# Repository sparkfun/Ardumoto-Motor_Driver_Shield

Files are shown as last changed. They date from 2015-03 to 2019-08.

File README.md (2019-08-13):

SparkFun Ardumoto - Motor Driver Shield
=======================================

SparkFun Ardumoto - Motor Driver Shield

[*SparkFun Ardumoto - Motor Driver Shield (DEV-14129)*](https://www.sparkfun.com/products/14129)

This is a motor shield for Arduino that will control two DC motors. 
Based on the L298 H-bridge, the SparkFun Ardumoto can drive up to 2 amps per channel. 

Repository Contents
-------------------
* **/Firmware** - Example Arduino sketch
* **/Hardware** - All Eagle design files (.brd, .sch)

Documentation
--------------
* [Hookup Guide](https://learn.sparkfun.com/tutorials/ardumoto-kit-hookup-guide)

Version History
---------------

* [HW_1.4_FW_1.0](https://github.com/sparkfun/Ardumoto-Motor_Driver_Shield/tree/HW_1.4_FW_1.0) - Version 1.4
* [V_2.0.0](https://github.com/sparkfun/Ardumoto-Motor_Driver_Shield/tree/V_2.0.0) - Initial build release
* [V_2.0.1](https://github.com/sparkfun/Ardumoto-Motor_Driver_Shield/tree/V_2.0.1) - Public release

License Information
-------------------
The hardware is released under [Creative Commons ShareAlike 4.0 International](https://creativecommons.org/licenses/by-sa/4.0/).
The code is beerware; if you see me (or any other SparkFun employee) at the local, and you've found our code helpful, please buy us a round!

Distributed as-is; no warranty is given.

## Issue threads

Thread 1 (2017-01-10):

Ardumoto_v15 Checklist

edspark, 2017-01-10:
1) Is there a SparkFun Logo? [YES]
comment: There are two logos on the second sheet, I'm not sure if you want them both.

2) Does it pass DRC with top/bottom keepout layers on? [YES]
comment: Plenty of approved erros centered around the many jumpers (funky library) and the 15 mill vias under the IC.

3) Are there airwires after ratsnest? [YES]
comment: I found two air wires and have attached images of them both.

4) Are measurements included for outer dimension and standoffs (Eagle layer 47)? [NO]
comment: There are missing measurements for the standoffs.

First air wire:
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

Second air wire:
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

marshalltaylorSFE, 2017-01-10:
1.  Switched sheets, moved one "logo" to the other sheet (these are really symbols to silk shapes)
2.  These approved violations are acceptable
3.  Airwires fixed!
4.  Measures added!

Closed 2017-01-10.

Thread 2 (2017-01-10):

Ardumoto Revision v15 Checklist

edspark, 2017-01-10:
1) If there are any DRC errors, have they all been approved? [YES]
comment: Many approved erros, double checked.

2) Is the designer name included in tDocu? [NO]
comment: "Pete Dokter" is not included in "Designed By"

3) Is any silkscreen overlaid on vias? [YES]
comment: Looks good for the silk that is partly covering vias.

marshalltaylorSFE, 2017-01-10:
1. OK
2. Name became buried under license after movement for measures, fixed.
3. "D7" is troublesome, but no better location is obvious, let's see how these look in proto hardware.

Closed 2017-01-10.

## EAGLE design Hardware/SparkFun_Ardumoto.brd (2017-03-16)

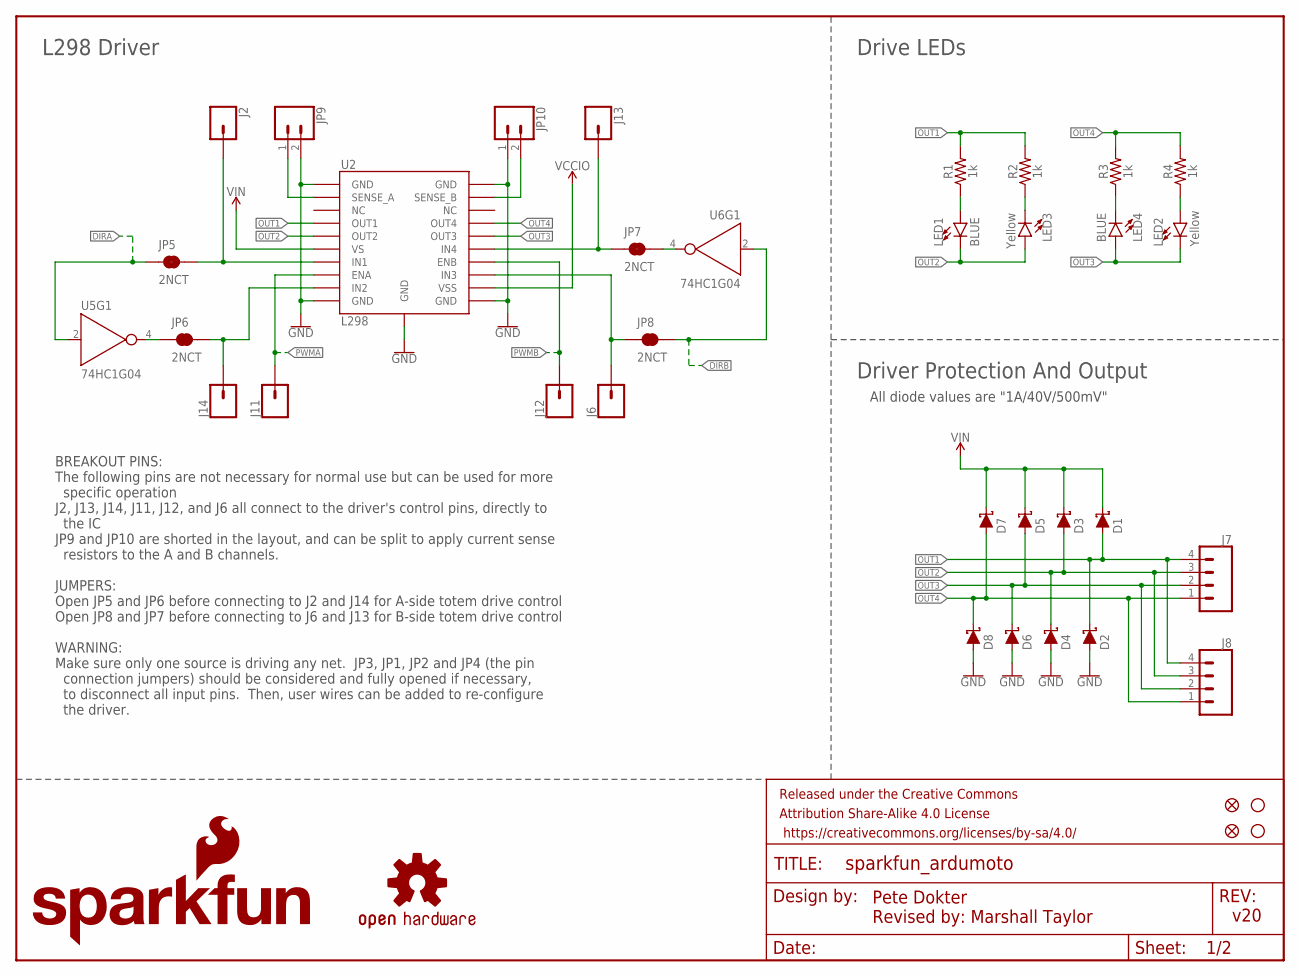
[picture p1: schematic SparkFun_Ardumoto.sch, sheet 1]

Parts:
D1, D2, D3, D4, D5, D6, D7, D8: 1A/40V/500mV; SMA-DIODE
FD1, FD2: FIDUCIALUFIDUCIAL; MICRO-FIDUCIAL
FRAME2: FRAME-LETTERNO_PACKAGE; DUMMY
H1, H2: STAND-OFF
J2, J6, J11, J12, J13, J14: CONN_01PTH_NO_SILK_YES_STOP; 1X01_NO_SILK
J7: CONN_04SCREW; SCREWTERMINAL-3.5MM-4
J8: CONN_04; 1X04
JP5, JP6, JP7, JP8: 2NCT; SMT-JUMPER_2_NC_TRACE_SILK
JP9, JP10: CONN_021X02_NO_SILK; 1X02_NO_SILK
LED1, LED4: BLUE; LED-0603
LED2, LED3: Yellow; LED-0603
LOGO2: SFE_LOGO_NAME_FLAME.1_INCH; SFE_LOGO_NAME_FLAME_.1
R1, R2, R3, R4: 1k; 0603
U2: L298; POWERSO20_L298_PAD
U5, U6: 74HC1G04; SOT353
U$1: OSHW-LOGOS; OSHW-LOGO-S

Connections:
DIRA: JP5.1, U5.2 (A); also elsewhere on the board
DIRB: JP8.2, U6.2 (A); also elsewhere on the board
GND: D2.A, D4.A, D6.A, D8.A, JP9.2, JP10.1, U2.1 (GND), U2.10 (GND), U2.11 (GND), U2.20 (GND), U2.PAD (GND); also elsewhere on the board
IN1: J2.1, JP5.2, U2.7 (IN1)
IN2: J14.1, JP6.2, U2.9 (IN2)
IN3: J6.1, JP8.1, U2.13 (IN3)
IN4: J13.1, JP7.1, U2.15 (IN4)
unnamed: LED1.A, R1.1
unnamed: LED3.C, R2.1
unnamed: LED4.C, R3.1
unnamed: LED2.A, R4.1
NDIRA: JP6.1, U5.4 (Y)
NDIRB: JP7.2, U6.4 (Y)
OUT1: D1.A, D2.C, J7.4, J8.4, R1.2, R2.2, U2.4 (OUT1)
OUT2: D3.A, D4.C, J7.3, J8.3, LED1.C, LED3.A, U2.5 (OUT2)
OUT3: D5.A, D6.C, J7.2, J8.2, LED2.C, LED4.A, U2.16 (OUT3)
OUT4: D7.A, D8.C, J7.1, J8.1, R3.2, R4.2, U2.17 (OUT4)
PWMA: J11.1, U2.8 (ENA); also elsewhere on the board
PWMB: J12.1, U2.14 (ENB); also elsewhere on the board
SENA: JP9.1, U2.2 (SENSE_A)
SENB: JP10.2, U2.19 (SENSE_B)
VCCIO: U2.12 (VSS); also elsewhere on the board
VIN: D1.C, D3.C, D5.C, D7.C, U2.6 (VS); also elsewhere on the board

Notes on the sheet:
v20
Revised by: Marshall Taylor
Pete Dokter
BREAKOUT PINS: The following pins are not necessary for normal use but can be used for more specific operation J2, J13, J14, J11, J12, and J6 all connect to the driver's control pins, directly to the IC JP9 and JP10 are shorted in the layout, and can be split to apply current sense resistors to the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
L298 Driver
Driver Protection And Output
Drive LEDs
All diode values are "1A/40V/500mV"

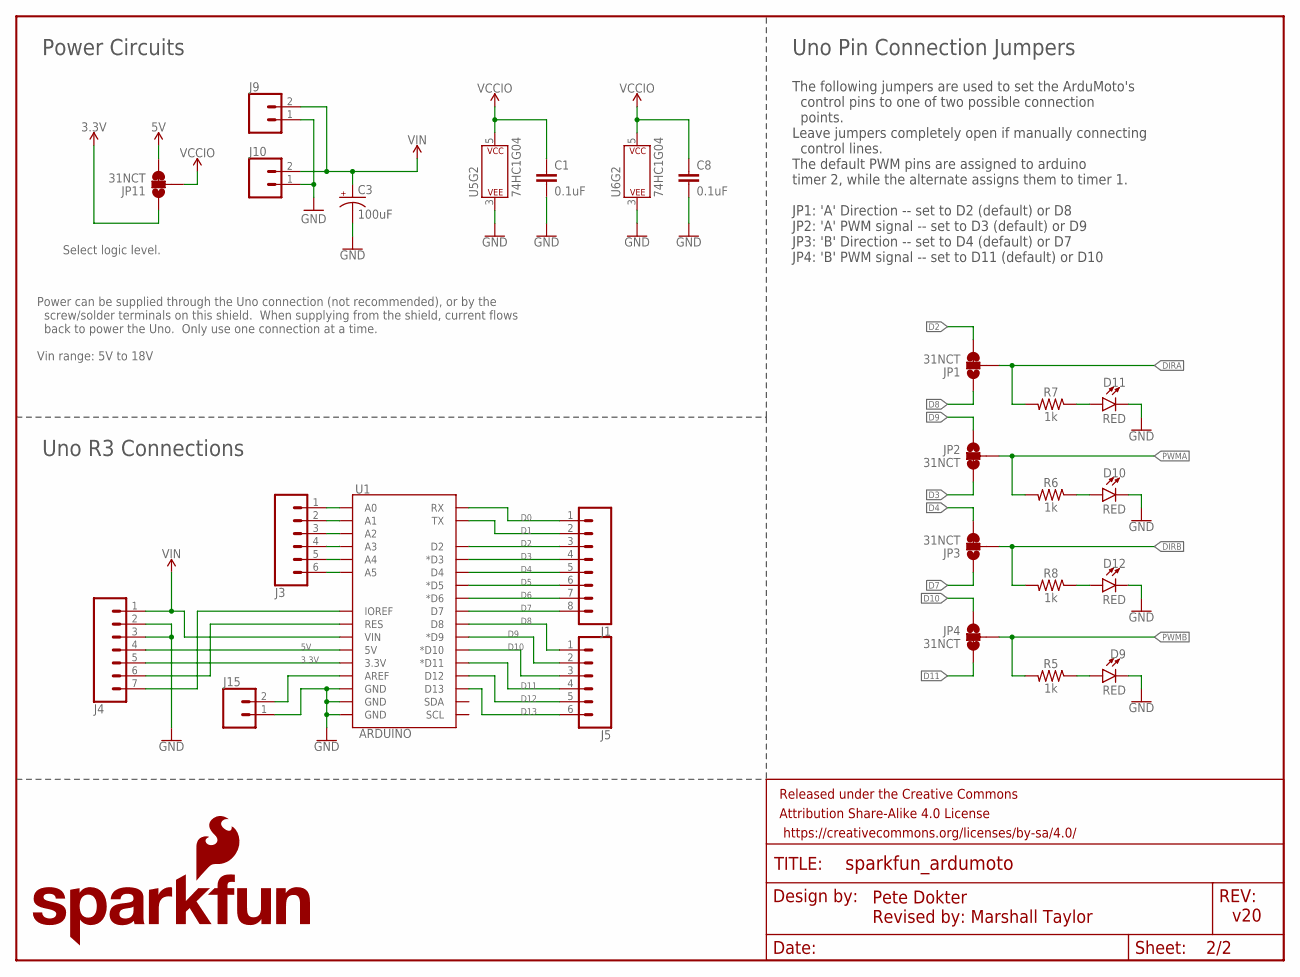
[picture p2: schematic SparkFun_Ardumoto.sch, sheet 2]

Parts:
C1, C8: 0.1uF; 0603
C3: 100uF; PANASONIC_D
D9, D10, D11, D12: RED; LED-0603
FRAME1: FRAME-LETTER; CREATIVE_COMMONS
J1: CONN_08NO_SILK_FEMALE_PTH; 1X08_NO_SILK
J3, J5: CONN_06NO_SILK_FEMALE_PTH; 1X06_NO_SILK
J4: CONN_07NO_SILK; 1X07_NO_SILK
J9: CONN_02; 1X02
J10: CONN_023.5MM; SCREWTERMINAL-3.5MM-2
J15: CONN_021X02_NO_SILK; 1X02_NO_SILK
JP1, JP2, JP3, JP4, JP11: 31NCT; SMT-JUMPER_3_1-NC_TRACE_SILK
LOGO1: SFE_LOGO_NAME_FLAME.2_INCH; SFE_LOGO_NAME_FLAME_.2
R5, R6, R7, R8: 1k; 0603
U1: ARDUINO; UNO_R3_SHIELD_NOLABELS
U5, U6: 74HC1G04; SOT353

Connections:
3.3V: J4.5, JP11.1, U1.3.3V
5V: J4.4, JP11.3, U1.5V
D0: J1.1, U1.RX
D1: J1.2, U1.TX
D2: J1.3, JP1.3, U1.D2
D3: J1.4, JP2.3, U1.D3 (*D3)
D4: J1.5, JP3.3, U1.D4
D5: J1.6, U1.D5 (*D5)
D6: J1.7, U1.D6 (*D6)
D7: J1.8, JP3.1, U1.D7
D8: J5.1, JP1.1, U1.D8
D9: J5.2, JP2.1, U1.D9 (*D9)
D10: J5.3, JP4.1, U1.D10 (*D10)
D11: J5.4, JP4.3, U1.D11 (*D11)
D12: J5.5, U1.D12
D13: J5.6, U1.D13
DIRA: JP1.2, R7.2; also elsewhere on the board
DIRB: JP3.2, R8.2; also elsewhere on the board
GND: C1.2, C3.-, C8.2, D9.C, D10.C, D11.C, D12.C, J4.2, J4.3, J9.1, J10.1, J15.1, U1.GND@0 (GND), U1.GND@1 (GND), U1.GND@2 (GND), U5.3 (P$V-), U6.3 (P$V-); also elsewhere on the board
IOREF: J4.7, U1.IOREF
unnamed: J15.2, U1.AREF
unnamed: J3.1, U1.A0
unnamed: J3.2, U1.A1
unnamed: J3.3, U1.A2
unnamed: J3.4, U1.A3
unnamed: J3.5, U1.A4
unnamed: J3.6, U1.A5
unnamed: D9.A, R5.1
unnamed: D10.A, R6.1
unnamed: D12.A, R8.1
unnamed: D11.A, R7.1
PWMA: JP2.2, R6.2; also elsewhere on the board
PWMB: JP4.2, R5.2; also elsewhere on the board
RESET: J4.6, U1.RES
VCCIO: C1.1, C8.1, JP11.2, U5.5 (P$V+), U6.5 (P$V+); also elsewhere on the board
VIN: C3.+, J4.1, J9.2, J10.2, U1.VIN; also elsewhere on the board

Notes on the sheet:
Power can be supplied through the Uno connection (not recommended), or by the screw/solder terminals on this shield. When supplying from the shield, current flows back to power the Uno. Only use one connection at a time. Vin range: 5V to 18V
v20
Revised by: Marshall Taylor
The following jumpers are used to set the ArduMoto's control pins to one of two possible connection points. Leave jumpers completely open if manually connecting control lines. The default PWM pins are assigned to arduino timer 2, while the alternate assigns them to timer 1. JP1: 'A' Direction -- se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
Power Circuits
Pete Dokter
Uno Pin Connection Jumpers
Uno R3 Connections
Select logic level.

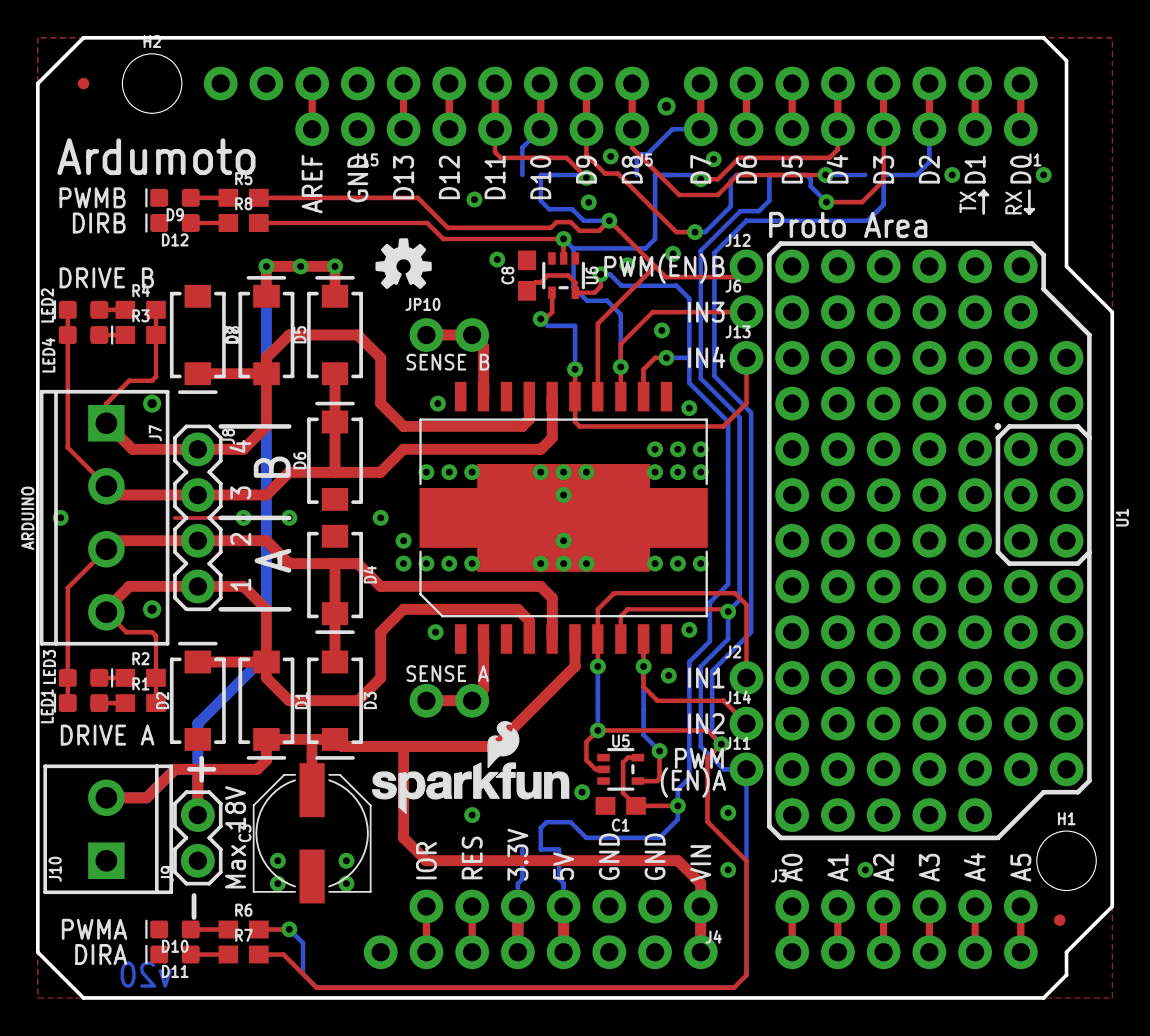
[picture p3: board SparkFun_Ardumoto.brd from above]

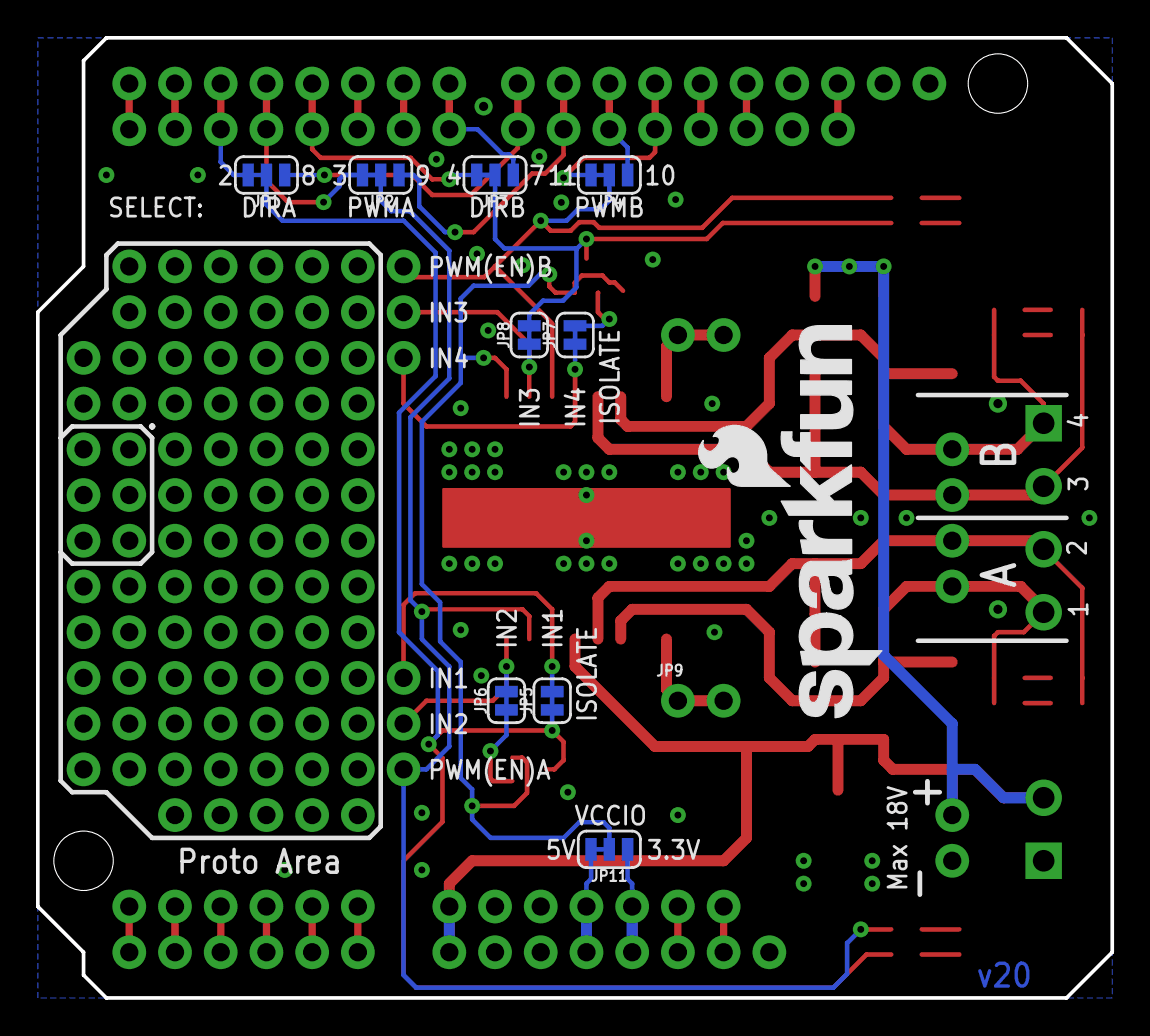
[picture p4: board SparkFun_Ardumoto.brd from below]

Board: 2 copper layers, 59.7 x 53.3 mm, 66 parts (11 on the bottom side), 52 nets.

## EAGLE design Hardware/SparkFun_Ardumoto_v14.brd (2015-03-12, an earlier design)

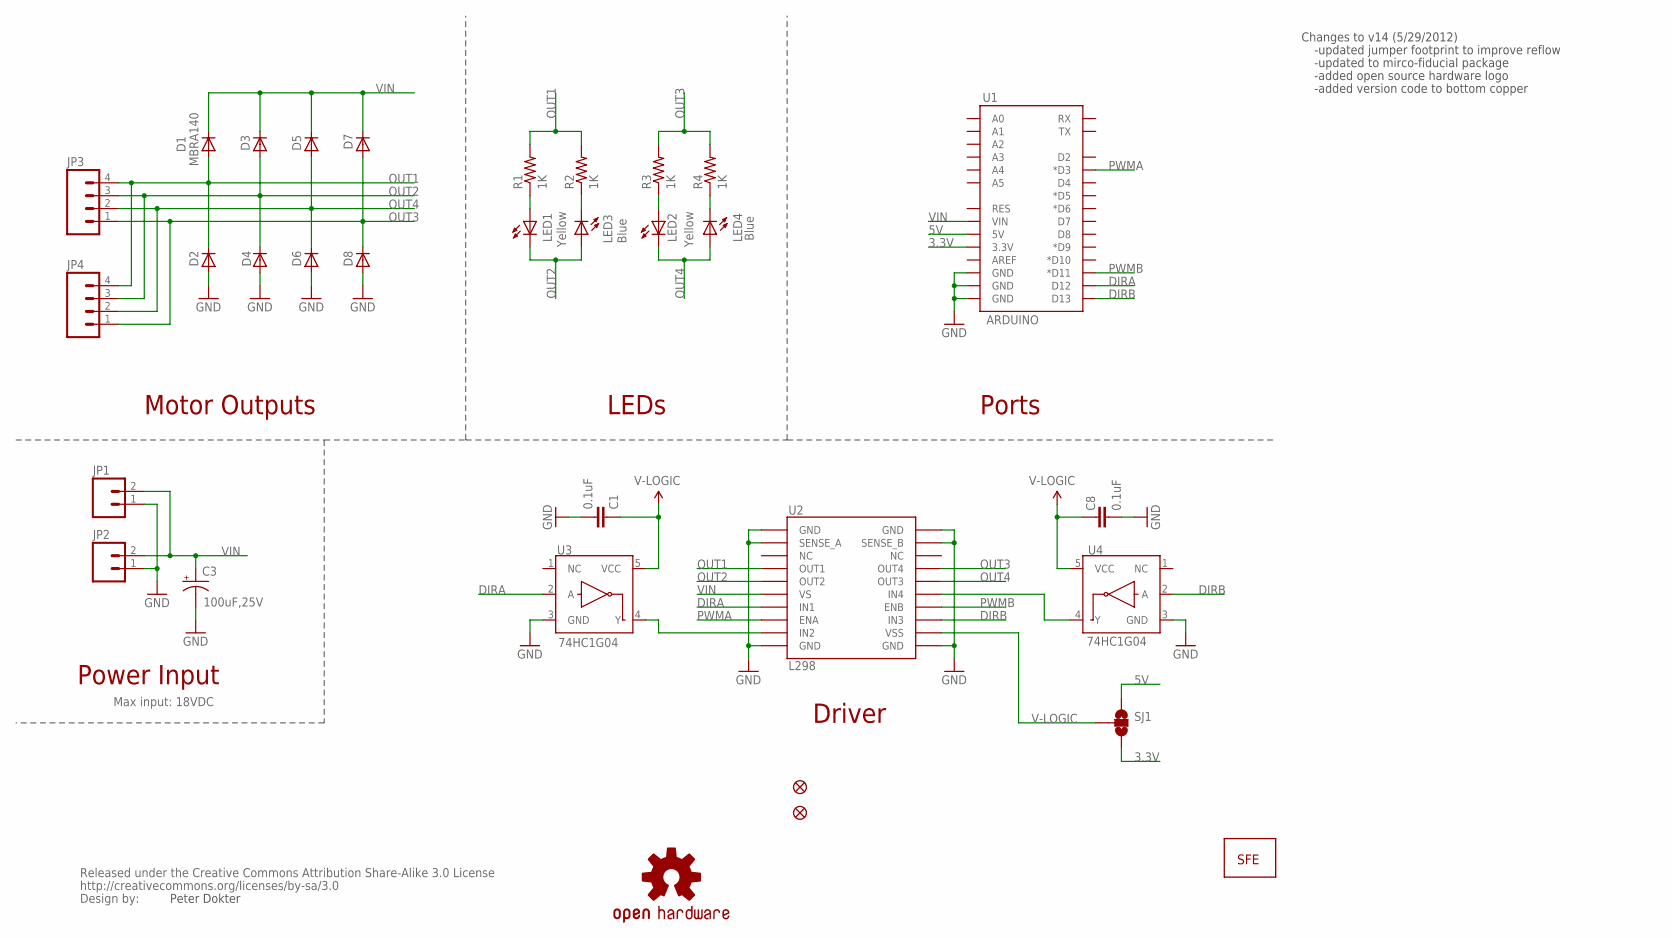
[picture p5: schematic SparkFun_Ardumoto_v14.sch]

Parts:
C1, C8: 0.1uF; 0402-CAP
C3: 100uF,25V; NIPPON_F80
D1, D2, D3, D4, D5, D6, D7, D8: MBRA140; SMA-DIODE
JP1: M02PTH; 1X02
JP2: M023.5MM; SCREWTERMINAL-3.5MM-2
JP3: M04SCREW; SCREWTERMINAL-3.5MM-4
JP4: M04PTH; 1X04
JP5, JP6: FIDUCIALUFIDUCIAL; MICRO-FIDUCIAL
LED1, LED2: Yellow; LED-0603
LED3, LED4: Blue; LED-0603
R1, R2, R3, R4: 1K; 0402-RES
SJ1: SOLDERJUMPER_2WAYPASTE1&2; SJ_3_PASTE1&2
U1: ARDUINO; DUEMILANOVE_SHIELD_NOLABELS
U2: L298; POWERSO20
U3, U4: 74HC1G04; SC70
U$1: OSHW-LOGOS; OSHW-LOGO-S
U$10: LOGO-SFENEW; SFE-NEW-WEBLOGO
U$11: CREATIVE_COMMONS

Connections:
3.3V: SJ1.3, U1.3.3V
5V: SJ1.1, U1.5V
DIRA: U1.D12, U2.7 (IN1), U3.2 (A)
DIRB: U1.D13, U2.13 (IN3), U4.2 (A)
GND: C1.2, C3.-, C8.2, D2.A, D4.A, D6.A, D8.A, JP1.1, JP2.1, U1.GND@0 (GND), U1.GND@1 (GND), U1.GND@2 (GND), U2.1 (GND), U2.2 (SENSE_A), U2.10 (GND), U2.11 (GND), U2.19 (SENSE_B), U2.20 (GND), U3.3 (GND), U4.3 (GND)
unnamed: U2.9 (IN2), U3.4 (Y)
unnamed: U2.15 (IN4), U4.4 (Y)
unnamed: LED1.A, R1.1
unnamed: LED3.C, R2.1
unnamed: LED2.A, R3.1
unnamed: LED4.C, R4.1
OUT1: D1.A, D2.C, JP3.4, JP4.4, R1.2, R2.2, U2.4 (OUT1)
OUT2: D3.A, D4.C, JP3.3, JP4.3, LED1.C, LED3.A, U2.5 (OUT2)
OUT3: D7.A, D8.C, JP3.1, JP4.1, R3.2, R4.2, U2.17 (OUT4)
OUT4: D5.A, D6.C, JP3.2, JP4.2, LED2.C, LED4.A, U2.16 (OUT3)
PWMA: U1.D3 (*D3), U2.8 (ENA)
PWMB: U1.D11 (*D11), U2.14 (ENB)
V-LOGIC: C1.1, C8.1, SJ1.2, U2.12 (VSS), U3.5 (VCC), U4.5 (VCC)
VIN: C3.+, D1.C, D3.C, D5.C, D7.C, JP1.2, JP2.2, U1.VIN, U2.6 (VS)

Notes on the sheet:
Motor Outputs
LEDs
Ports
Driver
Peter Dokter
Power Input
Max input: 18VDC
Changes to v14 (5/29/2012)
-updated jumper footprint to improve reflow
-updated to mirco-fiducial package
-added open source hardware logo
-added version code to bottom copper

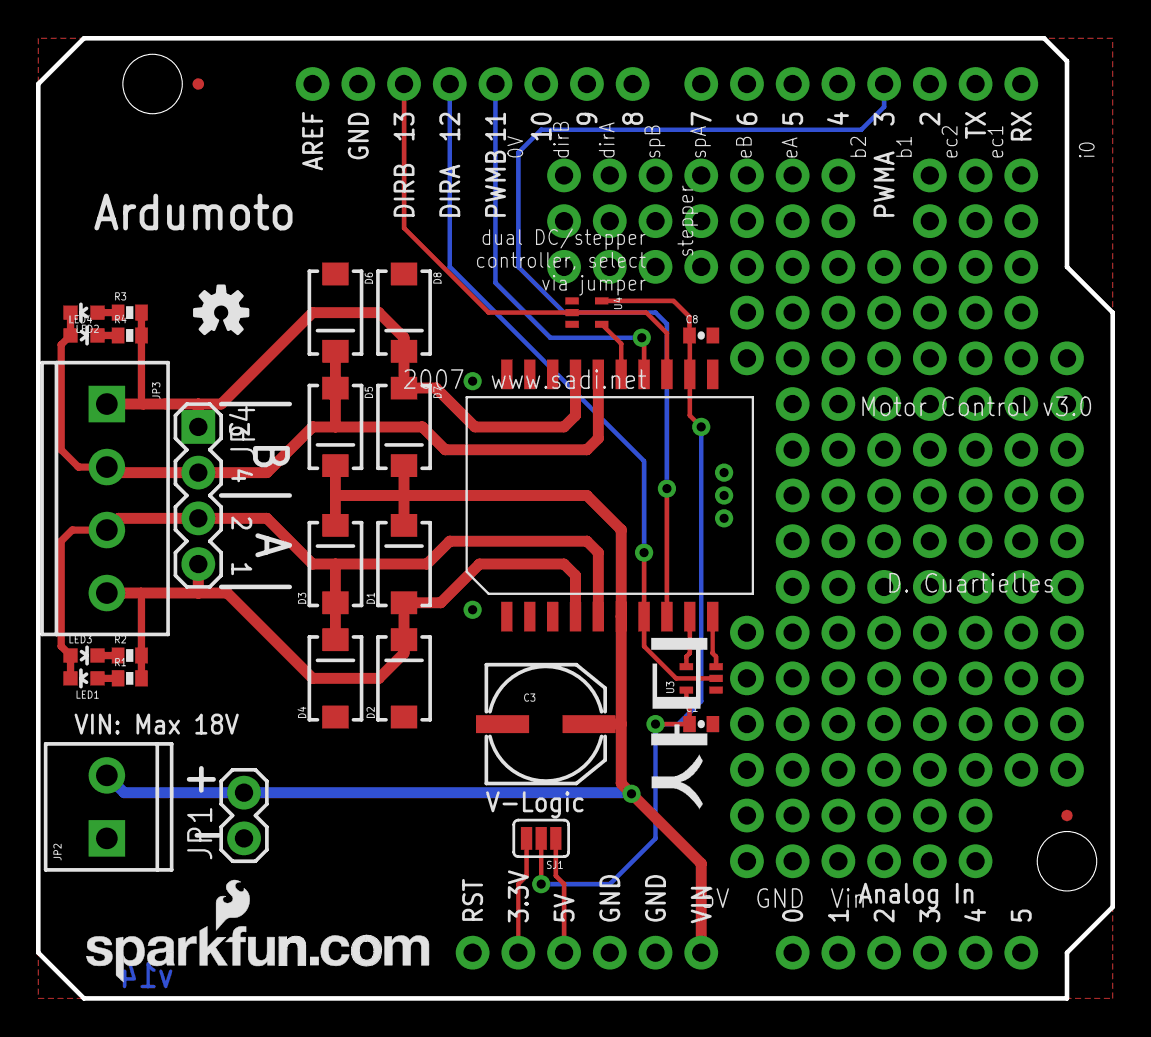
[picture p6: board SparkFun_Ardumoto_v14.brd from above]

Board: 2 copper layers, 59.7 x 53.3 mm, 33 parts (0 on the bottom side), 19 nets.

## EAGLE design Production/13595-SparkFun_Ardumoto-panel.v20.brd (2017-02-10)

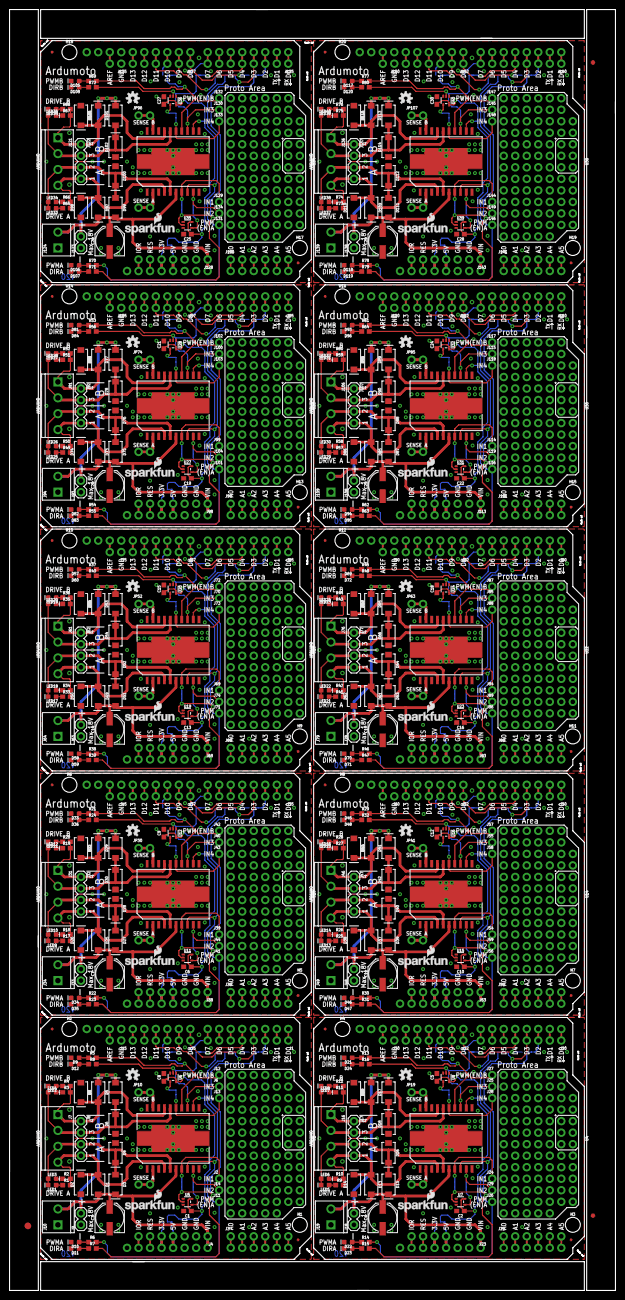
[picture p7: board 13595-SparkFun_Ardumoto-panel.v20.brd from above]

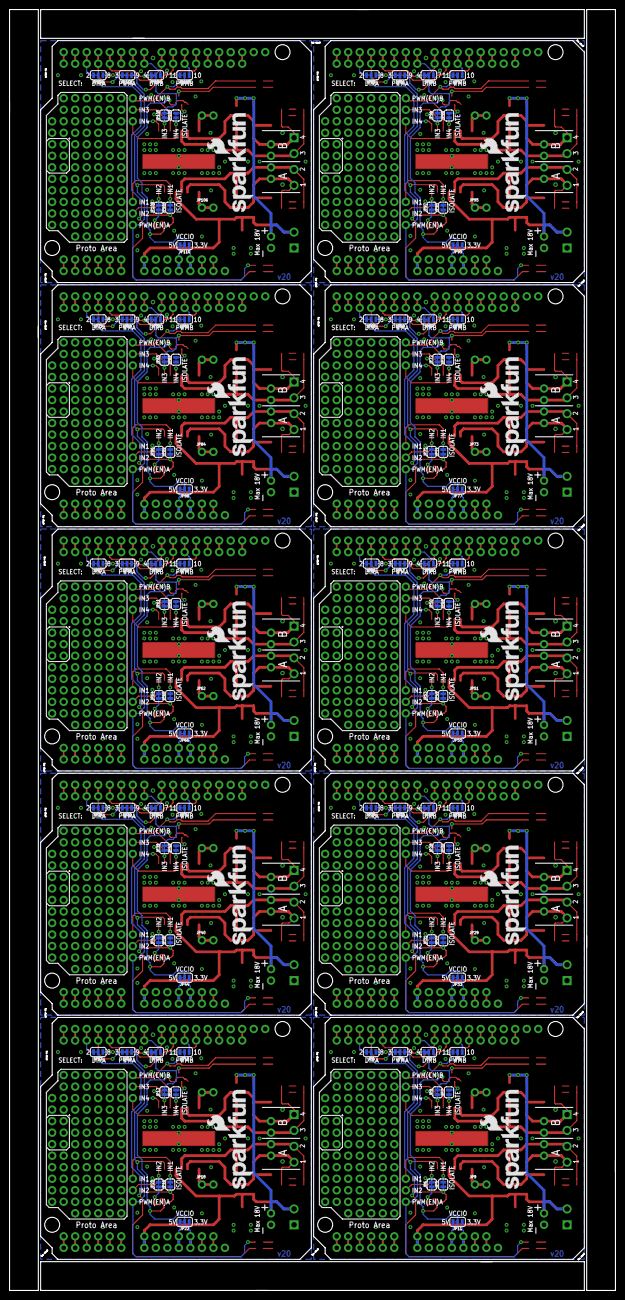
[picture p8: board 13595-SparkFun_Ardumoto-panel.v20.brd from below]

Board: 2 copper layers, 133.6 x 282.4 mm, 643 parts (110 on the bottom side), 520 nets.

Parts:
C1, C2, C5, C6, C8, C9, C10, C12, C13, C15, C16, C18, C19, C21, C22, C24, C25, C27, C28, C30: 0.1uF; 0603
C3, C4, C7, C11, C14, C17, C20, C23, C26, C29: 100uF; PANASONIC_D
D1, D2, D3, D4, D5, D6, D7, D8, D13, D14, D15, D16, D17, D18, D19, D20, D25, D26, D27, D28, D29, D30, D31, D32, D37, D38, D39, D40, D41, D42, D43, D44, D49, D50, D51, D52, D53, D54, D55, D56, D61, D62, D63, D64, D65, D66, D67, D68, D73, D74, D75, D76, D77, D78, D79, D80, D85, D86, D87, D88, D89, D90, D91, D92, D97, D98, D99, D100, D101, D102, D103, D104, D109, D110, D111, D112, D113, D114, D115, D116: 1A/40V/500mV; SMA-DIODE
D9, D10, D11, D12, D21, D22, D23, D24, D33, D34, D35, D36, D45, D46, D47, D48, D57, D58, D59, D60, D69, D70, D71, D72, D81, D82, D83, D84, D93, D94, D95, D96, D105, D106, D107, D108, D117, D118, D119, D120: RED; LED-0603
E$1: FIDUCIAL-1.5X3
E$7, E$8: FIDUCIAL-1X2
FD1, FD2, FD3, FD4, FD5, FD6, FD7, FD8, FD9, FD10, FD11, FD12, FD13, FD14, FD15, FD16, FD17, FD18, FD19, FD20: FIDUCIALUFIDUCIAL; MICRO-FIDUCIAL
H1, H2, H3, H4, H5, H6, H7, H8, H9, H10, H11, H12, H13, H14, H15, H16, H17, H18, H19, H20: STAND-OFF
J1, J20, J35, J50, J65, J80, J95, J110, J125, J140: 1X08_NO_SILK
J2, J6, J11, J12, J13, J14, J24, J25, J26, J27, J28, J29, J39, J40, J41, J42, J43, J44, J54, J55, J56, J57, J58, J59, J69, J70, J71, J72, J73, J74, J84, J85, J86, J87, J88, J89, J99, J100, J101, J102, J103, J104, J114, J115, J116, J117, J118, J119, J129, J130, J131, J132, J133, J134, J144, J145, J146, J147, J148, J149: 1X01_NO_SILK
J3, J5, J21, J22, J36, J37, J51, J52, J66, J67, J81, J82, J96, J97, J111, J112, J126, J127, J141, J142: 1X06_NO_SILK
J4, J23, J38, J53, J68, J83, J98, J113, J128, J143: 1X07_NO_SILK
J7, J16, J31, J46, J61, J76, J91, J106, J121, J136: SCREWTERMINAL-3.5MM-4
J8, J17, J32, J47, J62, J77, J92, J107, J122, J137: 1X04
J9, J18, J33, J48, J63, J78, J93, J108, J123, J138: 1X02
J10, J19, J34, J49, J64, J79, J94, J109, J124, J139: SCREWTERMINAL-3.5MM-2
J15, J30, J45, J60, J75, J90, J105, J120, J135, J150: 1X02_NO_SILK
JP1, JP2, JP3, JP4, JP11, JP12, JP13, JP14, JP15, JP22, JP23, JP24, JP25, JP26, JP33, JP34, JP35, JP36, JP37, JP44, JP45, JP46, JP47, JP48, JP55, JP56, JP57, JP58, JP59, JP66, JP67, JP68, JP69, JP70, JP77, JP78, JP79, JP80, JP81, JP88, JP89, JP90, JP91, JP92, JP99, JP100, JP101, JP102, JP103, JP110: 31NCT; SMT-JUMPER_3_1-NC_TRACE_SILK
JP5, JP6, JP7, JP8, JP16, JP17, JP20, JP21, JP27, JP28, JP31, JP32, JP38, JP39, JP42, JP43, JP49, JP50, JP53, JP54, JP60, JP61, JP64, JP65, JP71, JP72, JP75, JP76, JP82, JP83, JP86, JP87, JP93, JP94, JP97, JP98, JP104, JP105, JP108, JP109: 2NCT; SMT-JUMPER_2_NC_TRACE_SILK
JP9, JP10, JP18, JP19, JP29, JP30, JP40, JP41, JP51, JP52, JP62, JP63, JP73, JP74, JP84, JP85, JP95, JP96, JP106, JP107: 1X02_NO_SILK
LED1, LED2, LED5, LED7, LED9, LED11, LED13, LED15, LED17, LED19, LED21, LED23, LED25, LED27, LED29, LED31, LED33, LED35, LED37, LED39: Yellow; LED-0603
LED3, LED4, LED6, LED8, LED10, LED12, LED14, LED16, LED18, LED20, LED22, LED24, LED26, LED28, LED30, LED32, LED34, LED36, LED38, LED40: BLUE; LED-0603
LOGO1, LOGO3, LOGO5, LOGO7, LOGO9, LOGO11, LOGO13, LOGO15, LOGO17, LOGO19: SFE_LOGO_NAME_FLAME.2_INCH; SFE_LOGO_NAME_FLAME_.2
LOGO2, LOGO4, LOGO6, LOGO8, LOGO10, LOGO12, LOGO14, LOGO16, LOGO18, LOGO20: SFE_LOGO_NAME_FLAME.1_INCH; SFE_LOGO_NAME_FLAME_.1
R1, R2, R3, R4, R5, R6, R7, R8, R9, R10, R11, R12, R13, R14, R15, R16, R17, R18, R19, R20, R21, R22, R23, R24, R25, R26, R27, R28, R29, R30, R31, R32, R33, R34, R35, R36, R37, R38, R39, R40, R41, R42, R43, R44, R45, R46, R47, R48, R49, R50, R51, R52, R53, R54, R55, R56, R57, R58, R59, R60, R61, R62, R63, R64, R65, R66, R67, R68, R69, R70, R71, R72, R73, R74, R75, R76, R77, R78, R79, R80: 1k; 0603
U1, U4, U10, U14, U18, U22, U26, U30, U34, U38: ARDUINO; UNO_R3_SHIELD_NOLABELS
U2, U3, U9, U13, U17, U21, U25, U29, U33, U37: L298; POWERSO20_L298_PAD
U5, U6, U7, U8, U11, U12, U15, U16, U19, U20, U23, U24, U27, U28, U31, U32, U35, U36, U39, U40: 74HC1G04; SOT353
U$1, U$2, U$3, U$4, U$5, U$6, U$7, U$8, U$9, U$10: OSHW-LOGOS; OSHW-LOGO-S

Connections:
3.3V: J4.5, JP11.1, U1.3.3V
3.3V1: J23.5, JP22.1, U4.3.3V
3.3V2: J38.5, JP33.1, U10.3.3V
3.3V3: J53.5, JP44.1, U14.3.3V
3.3V4: J68.5, JP55.1, U18.3.3V
3.3V5: J83.5, JP66.1, U22.3.3V
3.3V6: J98.5, JP77.1, U26.3.3V
3.3V7: J113.5, JP88.1, U30.3.3V
3.3V8: J128.5, JP99.1, U34.3.3V
3.3V9: J143.5, JP110.1, U38.3.3V
5V: J4.4, JP11.3, U1.5V
5V1: J23.4, JP22.3, U4.5V
5V2: J38.4, JP33.3, U10.5V
5V3: J53.4, JP44.3, U14.5V
5V4: J68.4, JP55.3, U18.5V
5V5: J83.4, JP66.3, U22.5V
5V6: J98.4, JP77.3, U26.5V
5V7: J113.4, JP88.3, U30.5V
5V8: J128.4, JP99.3, U34.5V
5V9: J143.4, JP110.3, U38.5V
D0: J1.1, U1.RX
D1: J1.2, U1.TX
D2: J1.3, JP1.3, U1.D2
D3: J1.4, JP2.3, U1.D3
D4: J1.5, JP3.3, U1.D4
D5: J1.6, U1.D5
D6: J1.7, U1.D6
D7: J1.8, JP3.1, U1.D7
D8: J5.1, JP1.1, U1.D8
D9: J5.2, JP2.1, U1.D9
D10: J5.3, JP4.1, U1.D10
D11: J5.4, JP4.3, U1.D11
D12: J5.5, U1.D12
D13: J5.6, U1.D13
D14: J22.1, JP13.1, U4.D8
D15: J20.8, JP12.1, U4.D7
D16: J20.1, U4.RX
D17: J20.2, U4.TX
D18: J20.3, JP13.3, U4.D2
D19: J20.5, JP12.3, U4.D4
D20: J20.7, U4.D6
D21: J20.6, U4.D5
D22: J22.3, JP15.1, U4.D10
D23: J22.2, JP14.1, U4.D9
D24: J20.4, JP14.3, U4.D3
D25: J22.4, JP15.3, U4.D11
D26: J22.5, U4.D12
D27: J22.6, U4.D13
D28: J37.1, JP24.1, U10.D8
D29: J35.8, JP23.1, U10.D7
D30: J35.1, U10.RX
D31: J35.2, U10.TX
D32: J35.3, JP24.3, U10.D2
D33: J35.5, JP23.3, U10.D4
D34: J35.7, U10.D6
D35: J35.6, U10.D5
D36: J37.3, JP26.1, U10.D10
D37: J37.2, JP25.1, U10.D9
D38: J35.4, JP25.3, U10.D3
D39: J37.4, JP26.3, U10.D11
D40: J37.5, U10.D12
D41: J37.6, U10.D13
D42: J52.1, JP35.1, U14.D8
D43: J50.8, JP34.1, U14.D7
D44: J50.1, U14.RX
D45: J50.2, U14.TX
D46: J50.3, JP35.3, U14.D2
D47: J50.5, JP34.3, U14.D4
D48: J50.7, U14.D6
D49: J50.6, U14.D5
D50: J52.3, JP37.1, U14.D10
D51: J52.2, JP36.1, U14.D9
D52: J50.4, JP36.3, U14.D3
D53: J52.4, JP37.3, U14.D11
D54: J52.5, U14.D12
D55: J52.6, U14.D13
D56: J67.1, JP46.1, U18.D8
D57: J65.8, JP45.1, U18.D7
D58: J65.1, U18.RX
D59: J65.2, U18.TX
D60: J65.3, JP46.3, U18.D2
D61: J65.5, JP45.3, U18.D4
D62: J65.7, U18.D6
D63: J65.6, U18.D5
D64: J67.3, JP48.1, U18.D10
D65: J67.2, JP47.1, U18.D9
D66: J65.4, JP47.3, U18.D3
D67: J67.4, JP48.3, U18.D11
D68: J67.5, U18.D12
D69: J67.6, U18.D13
D70: J82.1, JP57.1, U22.D8
D71: J80.8, JP56.1, U22.D7
D72: J80.1, U22.RX
D73: J80.2, U22.TX
D74: J80.3, JP57.3, U22.D2
D75: J80.5, JP56.3, U22.D4
D76: J80.7, U22.D6
D77: J80.6, U22.D5
D78: J82.3, JP59.1, U22.D10
D79: J82.2, JP58.1, U22.D9
D80: J80.4, JP58.3, U22.D3
D81: J82.4, JP59.3, U22.D11
D82: J82.5, U22.D12
D83: J82.6, U22.D13
D84: J97.1, JP68.1, U26.D8
D85: J95.8, JP67.1, U26.D7
D86: J95.1, U26.RX
D87: J95.2, U26.TX
D88: J95.3, JP68.3, U26.D2
D89: J95.5, JP67.3, U26.D4
D90: J95.7, U26.D6
D91: J95.6, U26.D5
D92: J97.3, JP70.1, U26.D10
D93: J97.2, JP69.1, U26.D9
D94: J95.4, JP69.3, U26.D3
D95: J97.4, JP70.3, U26.D11
D96: J97.5, U26.D12
D97: J97.6, U26.D13
D98: J112.1, JP79.1, U30.D8
D99: J110.8, JP78.1, U30.D7
D100: J110.1, U30.RX
D101: J110.2, U30.TX
D102: J110.3, JP79.3, U30.D2
D103: J110.5, JP78.3, U30.D4
D104: J110.7, U30.D6
D105: J110.6, U30.D5
D106: J112.3, JP81.1, U30.D10
D107: J112.2, JP80.1, U30.D9
D108: J110.4, JP80.3, U30.D3
D109: J112.4, JP81.3, U30.D11
D110: J112.5, U30.D12
D111: J112.6, U30.D13
D112: J127.1, JP90.1, U34.D8
D113: J125.8, JP89.1, U34.D7
D114: J125.1, U34.RX
D115: J125.2, U34.TX
D116: J125.3, JP90.3, U34.D2
D117: J125.5, JP89.3, U34.D4
D118: J125.7, U34.D6
D119: J125.6, U34.D5
D120: J127.3, JP92.1, U34.D10
D121: J127.2, JP91.1, U34.D9
D122: J125.4, JP91.3, U34.D3
D123: J127.4, JP92.3, U34.D11
D124: J127.5, U34.D12
D125: J127.6, U34.D13
D126: J142.1, JP101.1, U38.D8
D127: J140.8, JP100.1, U38.D7
D128: J140.1, U38.RX
D129: J140.2, U38.TX
D130: J140.3, JP101.3, U38.D2
D131: J140.5, JP100.3, U38.D4
D132: J140.7, U38.D6
D133: J140.6, U38.D5
D134: J142.3, JP103.1, U38.D10
D135: J142.2, JP102.1, U38.D9
D136: J140.4, JP102.3, U38.D3
D137: J142.4, JP103.3, U38.D11
D138: J142.5, U38.D12
D139: J142.6, U38.D13
DIRA: JP1.2, JP5.1, R7.2, U5.2
DIRA1: JP13.2, JP16.1, R15.2, U7.2
DIRA2: JP24.2, JP27.1, R23.2, U11.2
DIRA3: JP35.2, JP38.1, R31.2, U15.2
DIRA4: JP46.2, JP49.1, R39.2, U19.2
DIRA5: JP57.2, JP60.1, R47.2, U23.2
DIRA6: JP68.2, JP71.1, R55.2, U27.2
DIRA7: JP79.2, JP82.1, R63.2, U31.2
DIRA8: JP90.2, JP93.1, R71.2, U35.2
DIRA9: JP101.2, JP104.1, R79.2, U39.2
DIRB: JP3.2, JP8.2, R8.2, U6.2
DIRB1: JP12.2, JP17.2, R16.2, U8.2
DIRB2: JP23.2, JP28.2, R24.2, U12.2
DIRB3: JP34.2, JP39.2, R32.2, U16.2
DIRB4: JP45.2, JP50.2, R40.2, U20.2
DIRB5: JP56.2, JP61.2, R48.2, U24.2
DIRB6: JP67.2, JP72.2, R56.2, U28.2
DIRB7: JP78.2, JP83.2, R64.2, U32.2
DIRB8: JP89.2, JP94.2, R72.2, U36.2
DIRB9: JP100.2, JP105.2, R80.2, U40.2
GND: C1.2, C3.-, C8.2, D2.A, D4.A, D6.A, D8.A, D9.C, D10.C, D11.C, D12.C, J4.2, J4.3, J9.1, J10.1, J15.1, JP9.2, JP10.1, U1.GND@0, U1.GND@1, U1.GND@2, U2.1, U2.10, U2.11, U2.20, U2.PAD, U5.3, U6.3
GND1: C2.2, C4.-, C5.2, D14.A, D16.A, D18.A, D20.A, D21.C, D22.C, D23.C, D24.C, J18.1, J19.1, J23.2, J23.3, J30.1, JP18.2, JP19.1, U3.1, U3.10, U3.11, U3.20, U3.PAD, U4.GND@0, U4.GND@1, U4.GND@2, U7.3, U8.3
GND2: C6.2, C7.-, C9.2, D26.A, D28.A, D30.A, D32.A, D33.C, D34.C, D35.C, D36.C, J33.1, J34.1, J38.2, J38.3, J45.1, JP29.2, JP30.1, U9.1, U9.10, U9.11, U9.20, U9.PAD, U10.GND@0, U10.GND@1, U10.GND@2, U11.3, U12.3
GND3: C10.2, C11.-, C12.2, D38.A, D40.A, D42.A, D44.A, D45.C, D46.C, D47.C, D48.C, J48.1, J49.1, J53.2, J53.3, J60.1, JP40.2, JP41.1, U13.1, U13.10, U13.11, U13.20, U13.PAD, U14.GND@0, U14.GND@1, U14.GND@2, U15.3, U16.3
GND4: C13.2, C14.-, C15.2, D50.A, D52.A, D54.A, D56.A, D57.C, D58.C, D59.C, D60.C, J63.1, J64.1, J68.2, J68.3, J75.1, JP51.2, JP52.1, U17.1, U17.10, U17.11, U17.20, U17.PAD, U18.GND@0, U18.GND@1, U18.GND@2, U19.3, U20.3
GND5: C16.2, C17.-, C18.2, D62.A, D64.A, D66.A, D68.A, D69.C, D70.C, D71.C, D72.C, J78.1, J79.1, J83.2, J83.3, J90.1, JP62.2, JP63.1, U21.1, U21.10, U21.11, U21.20, U21.PAD, U22.GND@0, U22.GND@1, U22.GND@2, U23.3, U24.3
GND6: C19.2, C20.-, C21.2, D74.A, D76.A, D78.A, D80.A, D81.C, D82.C, D83.C, D84.C, J93.1, J94.1, J98.2, J98.3, J105.1, JP73.2, JP74.1, U25.1, U25.10, U25.11, U25.20, U25.PAD, U26.GND@0, U26.GND@1, U26.GND@2, U27.3, U28.3
GND7: C22.2, C23.-, C24.2, D86.A, D88.A, D90.A, D92.A, D93.C, D94.C, D95.C, D96.C, J108.1, J109.1, J113.2, J113.3, J120.1, JP84.2, JP85.1, U29.1, U29.10, U29.11, U29.20, U29.PAD, U30.GND@0, U30.GND@1, U30.GND@2, U31.3, U32.3
GND8: C25.2, C26.-, C27.2, D98.A, D100.A, D102.A, D104.A, D105.C, D106.C, D107.C, D108.C, J123.1, J124.1, J128.2, J128.3, J135.1, JP95.2, JP96.1, U33.1, U33.10, U33.11, U33.20, U33.PAD, U34.GND@0, U34.GND@1, U34.GND@2, U35.3, U36.3
GND9: C28.2, C29.-, C30.2, D110.A, D112.A, D114.A, D116.A, D117.C, D118.C, D119.C, D120.C, J138.1, J139.1, J143.2, J143.3, J150.1, JP106.2, JP107.1, U37.1, U37.10, U37.11, U37.20, U37.PAD, U38.GND@0, U38.GND@1, U38.GND@2, U39.3, U40.3
IN1: J2.1, JP5.2, U2.7
IN2: J14.1, JP6.2, U2.9
IN3: J6.1, JP8.1, U2.13
IN4: J13.1, JP7.1, U2.15
IN5: J29.1, JP20.2, U3.9
IN6: J28.1, JP21.1, U3.15
IN7: J24.1, JP16.2, U3.7
IN8: J25.1, JP17.1, U3.13
IN9: J44.1, JP31.2, U9.9
IN10: J43.1, JP32.1, U9.15
IN11: J39.1, JP27.2, U9.7
IN12: J40.1, JP28.1, U9.13
IN13: J59.1, JP42.2, U13.9
IN14: J58.1, JP43.1, U13.15
IN15: J54.1, JP38.2, U13.7
IN16: J55.1, JP39.1, U13.13
IN17: J74.1, JP53.2, U17.9
IN18: J73.1, JP54.1, U17.15
IN19: J69.1, JP49.2, U17.7
IN20: J70.1, JP50.1, U17.13
IN21: J89.1, JP64.2, U21.9
IN22: J88.1, JP65.1, U21.15
IN23: J84.1, JP60.2, U21.7
IN24: J85.1, JP61.1, U21.13
IN25: J104.1, JP75.2, U25.9
IN26: J103.1, JP76.1, U25.15
IN27: J99.1, JP71.2, U25.7
IN28: J100.1, JP72.1, U25.13
IN29: J119.1, JP86.2, U29.9
IN30: J118.1, JP87.1, U29.15
IN31: J114.1, JP82.2, U29.7
IN32: J115.1, JP83.1, U29.13
IN33: J134.1, JP97.2, U33.9
IN34: J133.1, JP98.1, U33.15
IN35: J129.1, JP93.2, U33.7
IN36: J130.1, JP94.1, U33.13
IN37: J149.1, JP108.2, U37.9
IN38: J148.1, JP109.1, U37.15
IN39: J144.1, JP104.2, U37.7
IN40: J145.1, JP105.1, U37.13
IOREF: J4.7, U1.IOREF
IOREF1: J23.7, U4.IOREF
IOREF2: J38.7, U10.IOREF
IOREF3: J53.7, U14.IOREF
IOREF4: J68.7, U18.IOREF
IOREF5: J83.7, U22.IOREF
IOREF6: J98.7, U26.IOREF
IOREF7: J113.7, U30.IOREF
IOREF8: J128.7, U34.IOREF
IOREF9: J143.7, U38.IOREF
unnamed: LED1.A, R1.1
unnamed: LED3.C, R2.1
unnamed: LED4.C, R3.1
unnamed: LED2.A, R4.1
unnamed: J15.2, U1.AREF
unnamed: J3.1, U1.A0
unnamed: J3.2, U1.A1
unnamed: J3.3, U1.A2
unnamed: J3.4, U1.A3
unnamed: J3.5, U1.A4
unnamed: J3.6, U1.A5
unnamed: D9.A, R5.1
unnamed: D10.A, R6.1
unnamed: D12.A, R8.1
unnamed: D11.A, R7.1
unnamed: LED5.A, R9.1
unnamed: LED6.C, R10.1
unnamed: LED8.C, R11.1
unnamed: LED7.A, R12.1
unnamed: J21.1, U4.A0
unnamed: J21.2, U4.A1
unnamed: J21.3, U4.A2
unnamed: J21.4, U4.A3
unnamed: J21.5, U4.A4
unnamed: J21.6, U4.A5
unnamed: D21.A, R13.1
unnamed: D22.A, R14.1
unnamed: D24.A, R16.1
unnamed: D23.A, R15.1
unnamed: J30.2, U4.AREF
unnamed: LED9.A, R17.1
unnamed: LED10.C, R18.1
unnamed: LED12.C, R19.1
unnamed: LED11.A, R20.1
unnamed: J36.1, U10.A0
unnamed: J36.2, U10.A1
unnamed: J36.3, U10.A2
unnamed: J36.4, U10.A3
unnamed: J36.5, U10.A4
unnamed: J36.6, U10.A5
unnamed: D33.A, R21.1
unnamed: D34.A, R22.1
unnamed: D36.A, R24.1
unnamed: D35.A, R23.1
unnamed: J45.2, U10.AREF
unnamed: LED13.A, R25.1
unnamed: LED14.C, R26.1
unnamed: LED16.C, R27.1
unnamed: LED15.A, R28.1
unnamed: J51.1, U14.A0
unnamed: J51.2, U14.A1
unnamed: J51.3, U14.A2
unnamed: J51.4, U14.A3
unnamed: J51.5, U14.A4
unnamed: J51.6, U14.A5
unnamed: D45.A, R29.1
unnamed: D46.A, R30.1
unnamed: D48.A, R32.1
unnamed: D47.A, R31.1
unnamed: J60.2, U14.AREF
unnamed: LED17.A, R33.1
unnamed: LED18.C, R34.1
unnamed: LED20.C, R35.1
unnamed: LED19.A, R36.1
unnamed: J66.1, U18.A0
unnamed: J66.2, U18.A1
unnamed: J66.3, U18.A2
unnamed: J66.4, U18.A3
unnamed: J66.5, U18.A4
unnamed: J66.6, U18.A5
unnamed: D57.A, R37.1
unnamed: D58.A, R38.1
unnamed: D60.A, R40.1
unnamed: D59.A, R39.1
unnamed: J75.2, U18.AREF
unnamed: LED21.A, R41.1
unnamed: LED22.C, R42.1
unnamed: LED24.C, R43.1
unnamed: LED23.A, R44.1
unnamed: J81.1, U22.A0
unnamed: J81.2, U22.A1
unnamed: J81.3, U22.A2
unnamed: J81.4, U22.A3
unnamed: J81.5, U22.A4
unnamed: J81.6, U22.A5
unnamed: D69.A, R45.1
unnamed: D70.A, R46.1
unnamed: D72.A, R48.1
unnamed: D71.A, R47.1
unnamed: J90.2, U22.AREF
unnamed: LED25.A, R49.1
unnamed: LED26.C, R50.1
unnamed: LED28.C, R51.1
unnamed: LED27.A, R52.1
unnamed: J96.1, U26.A0
unnamed: J96.2, U26.A1
unnamed: J96.3, U26.A2
unnamed: J96.4, U26.A3
unnamed: J96.5, U26.A4
unnamed: J96.6, U26.A5
unnamed: D81.A, R53.1
unnamed: D82.A, R54.1
unnamed: D84.A, R56.1
unnamed: D83.A, R55.1
unnamed: J105.2, U26.AREF
unnamed: LED29.A, R57.1
unnamed: LED30.C, R58.1
unnamed: LED32.C, R59.1
unnamed: LED31.A, R60.1
unnamed: J111.1, U30.A0
unnamed: J111.2, U30.A1
unnamed: J111.3, U30.A2
unnamed: J111.4, U30.A3
unnamed: J111.5, U30.A4
unnamed: J111.6, U30.A5
unnamed: D93.A, R61.1
unnamed: D94.A, R62.1
unnamed: D96.A, R64.1
unnamed: D95.A, R63.1
unnamed: J120.2, U30.AREF
unnamed: LED33.A, R65.1
unnamed: LED34.C, R66.1
unnamed: LED36.C, R67.1
unnamed: LED35.A, R68.1
unnamed: J126.1, U34.A0
unnamed: J126.2, U34.A1
unnamed: J126.3, U34.A2
unnamed: J126.4, U34.A3
unnamed: J126.5, U34.A4
unnamed: J126.6, U34.A5
unnamed: D105.A, R69.1
unnamed: D106.A, R70.1
unnamed: D108.A, R72.1
unnamed: D107.A, R71.1
unnamed: J135.2, U34.AREF
unnamed: LED37.A, R73.1
unnamed: LED38.C, R74.1
unnamed: LED40.C, R75.1
unnamed: LED39.A, R76.1
unnamed: J141.1, U38.A0
unnamed: J141.2, U38.A1
unnamed: J141.3, U38.A2
unnamed: J141.4, U38.A3
unnamed: J141.5, U38.A4
unnamed: J141.6, U38.A5
unnamed: D117.A, R77.1
unnamed: D118.A, R78.1
unnamed: D120.A, R80.1
unnamed: D119.A, R79.1
unnamed: J150.2, U38.AREF
NDIRA: JP6.1, U5.4
NDIRA1: JP20.1, U7.4
NDIRA2: JP31.1, U11.4
NDIRA3: JP42.1, U15.4
NDIRA4: JP53.1, U19.4
NDIRA5: JP64.1, U23.4
NDIRA6: JP75.1, U27.4
NDIRA7: JP86.1, U31.4
NDIRA8: JP97.1, U35.4
NDIRA9: JP108.1, U39.4
NDIRB: JP7.2, U6.4
NDIRB1: JP21.2, U8.4
NDIRB2: JP32.2, U12.4
NDIRB3: JP43.2, U16.4
NDIRB4: JP54.2, U20.4
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

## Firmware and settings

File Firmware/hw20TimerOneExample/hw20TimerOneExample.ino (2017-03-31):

//This sketch walks through various drive states.
//Use the serial terminal to advance states.  Enter some serial data and press return.
//The sketch only check for the existance of data, not what it is.
//
//The Ardumoto must have all pins set to alternate, timer1 only works on
//pins 9 and 10.
//
//Marshall Taylor
//March 3, 2017

#include "TimerOne.h"

// Clockwise and counter-clockwise definitions.
// Depending on how you wired your motors, you may need to swap.
#define FORWARD  0
#define REVERSE 1

	// Motor definitions to make life easier:
#define MOTOR_A 0
#define MOTOR_B 1

// Pin Assignments //
// Timer1 connects only to PWM pins 9 and 10.

//Alternate pins:
#define DIRA 8 // Direction control for motor A
#define PWMA 9 // PWM control (speed) for motor A
#define DIRB 7 // Direction control for motor B
#define PWMB 10 // PWM control (speed) for motor B

void setup()
{
	Serial.begin(115200);
	setupArdumoto(); // Set all pins as outputs
}

void loop()
{
	int loopRunning = 1;
	int counter = 0;
	int state = 0;
	while( loopRunning == 1 )
	{
		//ramp up
		switch( state )
		{
		case 0:
			driveArdumoto(MOTOR_A, FORWARD, counter);
			driveArdumoto(MOTOR_B, FORWARD, counter);
			counter++;
			if( counter == 256 )
			{
				counter = 255;
				state = 1;
			}
			break;
		case 1:
			driveArdumoto(MOTOR_A, FORWARD, counter);
			driveArdumoto(MOTOR_B, FORWARD, counter);
			counter--;
			if( counter == 1 )
			{
				counter = 0;
				state = 0;
			}
			break;
		case 2:
			break;
		default:
			break;
		}
		delay(3);
		if( Serial.available() )
		{
			loopRunning = 0;
		}
	}
	waitForInput();

	// Now spin both!
	driveArdumoto(MOTOR_A, FORWARD, 255);  // Motor A at max speed.
	driveArdumoto(MOTOR_B, FORWARD, 255);  // Motor B at max speed.
	waitForInput();

	// Now go backwards at half that speed:
	driveArdumoto(MOTOR_A, REVERSE, 127);  // Motor A at max speed.
	driveArdumoto(MOTOR_B, REVERSE, 127);  // Motor B at max speed.
	waitForInput();
	
	stopArdumoto(MOTOR_A);  // STOP motor A 
	stopArdumoto(MOTOR_B);  // STOP motor A 
	waitForInput();
}

// driveArdumoto drives 'motor' in 'dir' direction at 'spd' speed
void driveArdumoto(byte motor, byte dir, byte spd)
{
	if (motor == MOTOR_A)
	{
		digitalWrite(DIRA, dir);
		//analogWrite(PWMA, spd);
		Timer1.pwm(PWMA, spd << 2);
	}
	else if (motor == MOTOR_B)
	{
		digitalWrite(DIRB, dir);
		//analogWrite(PWMB, spd);
		Timer1.pwm(PWMB, spd << 2);
	}  
}

// stopArdumoto makes a motor stop
void stopArdumoto(byte motor)
{
	driveArdumoto(motor, 0, 0);
}

// setupArdumoto initialize all pins
void setupArdumoto()
{
	// All pins should be setup as outputs:
	pinMode(PWMA, OUTPUT);
	pinMode(PWMB, OUTPUT);
	pinMode(DIRA, OUTPUT);
	pinMode(DIRB, OUTPUT);

	// Initialize all pins as low:
	digitalWrite(PWMA, LOW);
	digitalWrite(PWMB, LOW);
	digitalWrite(DIRA, LOW);
	digitalWrite(DIRB, LOW);
 
	Timer1.initialize(200);         // initialize timer1

}

void waitForInput( void )
{
	while( Serial.available() == 0 )
	{
		delay(1);
	}
	while( Serial.available() == 1 )
	{
		Serial.read();
		delay(1);
	}
}

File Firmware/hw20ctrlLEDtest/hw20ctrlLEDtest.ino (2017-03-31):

//Ardumoto test sketch

//This sketch tests control and status LEDs

//The sketch walks through both default and alternate pins.  It sends
//serial data indicating which LEDs should be lit for a configuration,
//then waits for user input before continuing.

//Please do not connect any motors to the driver.

//(This is also the source location for pin defines)

//// Pin Assignments //
////Default pins:
//#define DIRA 2 // Direction control for motor A
//#define PWMA 3  // PWM control (speed) for motor A
//#define DIRB 4 // Direction control for motor B
//#define PWMB 11 // PWM control (speed) for motor B
//
//////Alternate pins:
////#define DIRA 8 // Direction control for motor A
////#define PWMA 9 // PWM control (speed) for motor A
////#define DIRB 7 // Direction control for motor B
////#define PWMB 10 // PWM control (speed) for motor B

//Test specific namings:
#define DIRA 2 // Direction control for motor A
#define PWMA 3  // PWM control (speed) for motor A
#define DIRB 4 // Direction control for motor B
#define PWMB 11 // PWM control (speed) for motor B
#define ALT_DIRA 8 // Direction control for motor A
#define ALT_PWMA 9 // PWM control (speed) for motor A
#define ALT_DIRB 7 // Direction control for motor B
#define ALT_PWMB 10 // PWM control (speed) for motor B



void setup()
{
	Serial.begin(115200);
}

void loop()
{
	//Set up for standard
	pinMode(PWMA, OUTPUT);
	pinMode(PWMB, OUTPUT);
	pinMode(DIRA, OUTPUT);
	pinMode(DIRB, OUTPUT);
	digitalWrite(PWMA, LOW);
	digitalWrite(PWMB, LOW);
	digitalWrite(DIRA, LOW);
	digitalWrite(DIRB, LOW);
	Serial.println("Testing default mode:");
	
	//Display PWMA
	Serial.println("PWMA should be lit, Drive A should be orange");
	digitalWrite(PWMA, HIGH);
	waitForInput();

	//Display PWMA and DIRA
	Serial.println("PWMA and DIRA should be lit, Drive A should be blue");
	digitalWrite(DIRA, HIGH);
	waitForInput();
	digitalWrite(PWMA, LOW);
	digitalWrite(DIRA, LOW);
	
	//Display PWMB
	Serial.println("PWMB should be lit, Drive B should be orange");
	digitalWrite(PWMB, HIGH);
	waitForInput();

	//Display PWMB and DIRA
	Serial.println("PWMB and DIRB should be lit, Drive B should be blue");
	digitalWrite(DIRB, HIGH);
	waitForInput();
	digitalWrite(PWMB, LOW);
	digitalWrite(DIRB, LOW);	

	pinMode(PWMA, INPUT);
	pinMode(PWMB, INPUT);
	pinMode(DIRA, INPUT);
	pinMode(DIRB, INPUT);
	
	//Set up for standard
	pinMode(ALT_PWMA, OUTPUT);
	pinMode(ALT_PWMB, OUTPUT);
	pinMode(ALT_DIRA, OUTPUT);
	pinMode(ALT_DIRB, OUTPUT);
	digitalWrite(ALT_PWMA, LOW);
	digitalWrite(ALT_PWMB, LOW);
	digitalWrite(ALT_DIRA, LOW);
	digitalWrite(ALT_DIRB, LOW);
	
	Serial.println("Testing alternate mode:");
	
	//Display PWMA
	Serial.println("PWMA should be lit, Drive A should be orange");
	digitalWrite(ALT_PWMA, HIGH);
	waitForInput();

	//Display PWMA and DIRA
	Serial.println("PWMA and DIRA should be lit, Drive A should be blue");
	digitalWrite(ALT_DIRA, HIGH);
	waitForInput();
	digitalWrite(ALT_PWMA, LOW);
	digitalWrite(ALT_DIRA, LOW);
	
	//Display PWMB
	Serial.println("PWMB should be lit, Drive B should be orange");
	digitalWrite(ALT_PWMB, HIGH);
	waitForInput();

	//Display PWMB and DIRA
	Serial.println("PWMB and DIRB should be lit, Drive B should be blue");
	digitalWrite(ALT_DIRB, HIGH);
	waitForInput();
	digitalWrite(ALT_PWMB, LOW);
	digitalWrite(ALT_DIRB, LOW);	

	pinMode(ALT_PWMA, INPUT);
	pinMode(ALT_PWMB, INPUT);
	pinMode(ALT_DIRA, INPUT);
	pinMode(ALT_DIRB, INPUT);

	
}


void waitForInput( void )
{
	while( Serial.available() == 0 )
	{
		delay(1);
	}
	while( Serial.available() == 1 )
	{
		Serial.read();
		delay(1);
	}
}

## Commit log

2015-03-12 Adding hardware files for real this time
    [SparkFun_Ardumoto_v14.brd, SparkFun_Ardumoto_v14.sch]
2016-12-20 Schematic is the same, but all parts have been updated to the new libraries. The layout is no longer valid, and proto area has been moved aside. This is ready for functional changes.
    [SparkFun_Ardumoto.brd, SparkFun_Ardumoto.sch]
2016-12-21 Schematic changes applied, layout is now mostly ripped up
    [SparkFun_Ardumoto.brd, SparkFun_Ardumoto.sch]
2016-12-29 Desing ready for proto 1 review
    [Configurations.ods, SparkFun_Ardumoto.brd, SparkFun_Ardumoto.sch]
2017-01-06 Touched up the silk a bit in preparation for review
    [SparkFun_Ardumoto.brd, SparkFun_Ardumoto.sch]
2017-01-09 Going for QC inspection
    [SparkFun_Ardumoto.brd, SparkFun_Ardumoto.sch]
2017-01-10 Reordered two R3 pins (9 and 6). Switched sheet locations and adjusted logos. Removed invalid airwires
    [SparkFun_Ardumoto.brd, SparkFun_Ardumoto.sch]
2017-01-10 Moved designer name back into place, checked silk
    [SparkFun_Ardumoto.brd]
2017-02-07 Made changes to prototype in preparation for reds
    [SparkFun_Ardumoto.brd, SparkFun_Ardumoto.sch]
2017-02-07 Added note on VCCIO and nudged traces
    [SparkFun_Ardumoto.brd, SparkFun_Ardumoto.sch]
2017-02-08 Made post-review changes
    [SparkFun_Ardumoto.brd, SparkFun_Ardumoto.sch]
2017-03-16 switched components LED1 and LED3
    [SparkFun_Ardumoto.brd, SparkFun_Ardumoto.sch]

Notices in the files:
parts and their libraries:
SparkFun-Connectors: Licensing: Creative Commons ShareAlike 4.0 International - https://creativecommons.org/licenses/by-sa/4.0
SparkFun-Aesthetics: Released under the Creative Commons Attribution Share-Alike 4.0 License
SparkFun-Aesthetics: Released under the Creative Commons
